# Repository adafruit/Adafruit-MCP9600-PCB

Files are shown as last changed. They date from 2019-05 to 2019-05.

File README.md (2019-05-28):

# Adafruit-MCP9600-PCB
PCB files for Adafruit MCP9600

Format is EagleCAD schematic and board layout

For more details, check out the product page at

   * https://www.adafruit.com/product/4101

Adafruit invests time and resources providing this open source design, 
please support Adafruit and open-source hardware by purchasing 
products from Adafruit!

Designed by Adafruit Industries.  
Creative Commons Attribution, Share-Alike license, check license.txt for more information
All text above must be included in any redistribution

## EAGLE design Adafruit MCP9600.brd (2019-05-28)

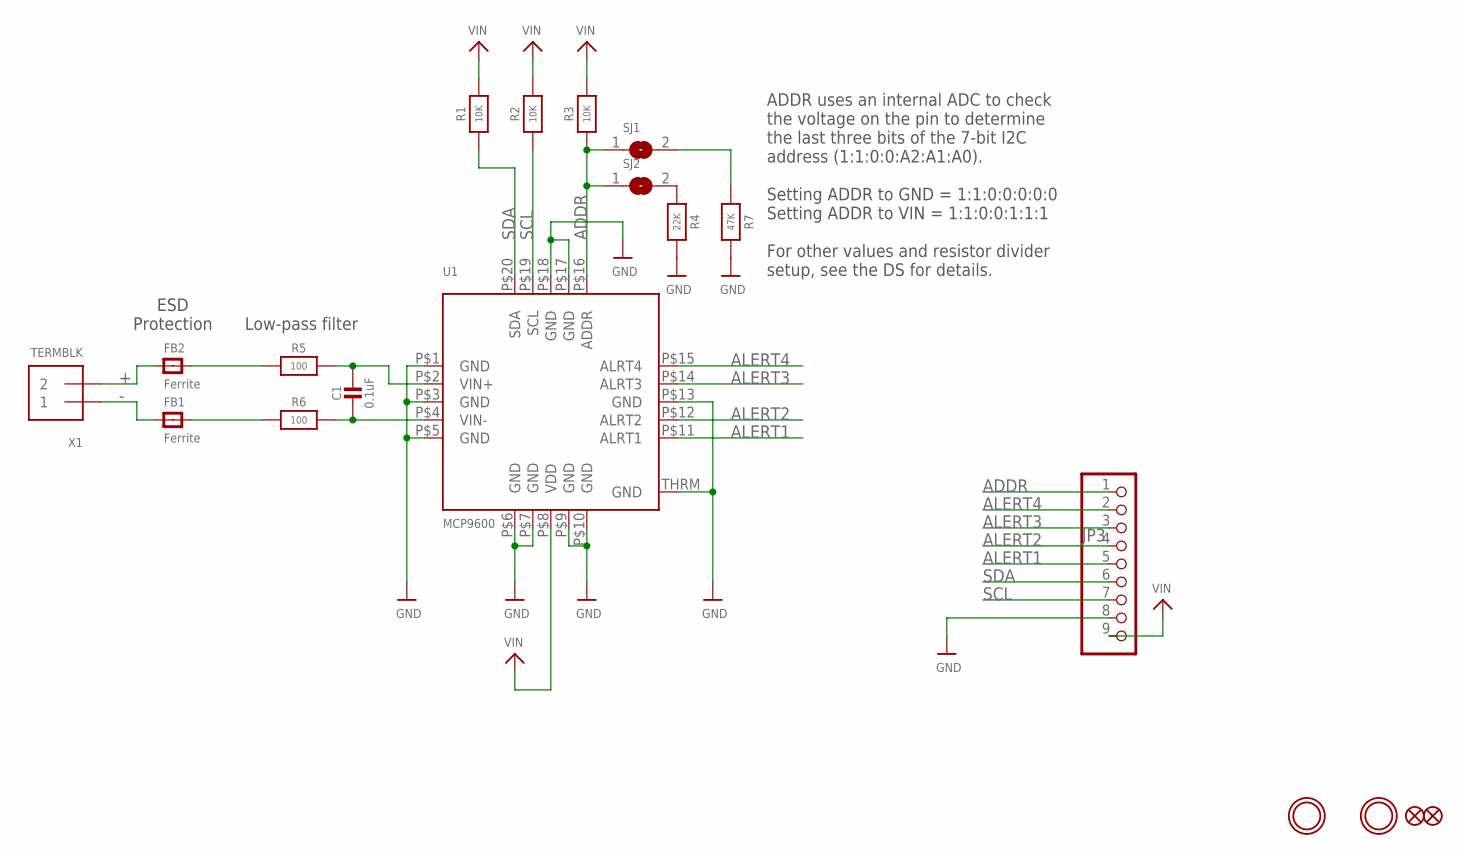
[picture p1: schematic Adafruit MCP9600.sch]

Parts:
C1: 0.1uF; 0603-NO
FB1, FB2: Ferrite; 0805-NO
FID1, FID2: FIDUCIAL_1MM
JP3: HEADER-1X970MIL; 1X09_ROUND_70
R1, R2, R3: 10K; 0603-NO
R4: 22K; 0603-NO
R5, R6: 100; 0603-NO
R7: 47K; 0603-NO
SJ1, SJ2: SOLDERJUMPER; SOLDERJUMPER_ARROW_NOPASTE
U1: MCP9600; VQFN20_5MM
U$1, U$3: MOUNTINGHOLE2.5; MOUNTINGHOLE_2.5_PLATED
X1: TERMBLK; TERMBLOCK_1X2-3.5MM

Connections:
+: FB2.1, X1.2
-: FB1.1, X1.1
ADDR: JP3.1, R3.1, SJ1.1, SJ2.1, U1.P$16 (ADDR)
ALERT1: JP3.5, U1.P$11 (ALRT1)
ALERT2: JP3.4, U1.P$12 (ALRT2)
ALERT3: JP3.3, U1.P$14 (ALRT3)
ALERT4: JP3.2, U1.P$15 (ALRT4)
GND: JP3.8, R4.2, R7.2, U1.P$1 (GND), U1.P$3 (GND), U1.P$5 (GND), U1.P$6 (GND), U1.P$7 (GND), U1.P$9 (GND), U1.P$10 (GND), U1.P$13 (GND), U1.P$17 (GND), U1.P$18 (GND), U1.THRM (GND)
unnamed: C1.1, R5.2, U1.P$2 (VIN+)
unnamed: C1.2, R6.2, U1.P$4 (VIN-)
unnamed: FB1.2, R6.1
unnamed: FB2.2, R5.1
unnamed: R7.1, SJ1.2
unnamed: R4.1, SJ2.2
SCL: JP3.7, R2.1, U1.P$19 (SCL)
SDA: JP3.6, R1.1, U1.P$20 (SDA)
VIN: JP3.9, R1.2, R2.2, R3.2, U1.P$8 (VDD)

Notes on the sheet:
ADDR uses an internal ADC to check the voltage on the pin to determine the last three bits of the 7-bit I2C address (1:1:0:0:A2:A1:A0). Setting ADDR to GND = 1:1:0:0:0:0:0 Setting ADDR to VIN = 1:1:0:0:1:1:1 For other values and resistor divider setup, see the DS for details.
Low-pass filter
ESD Protection

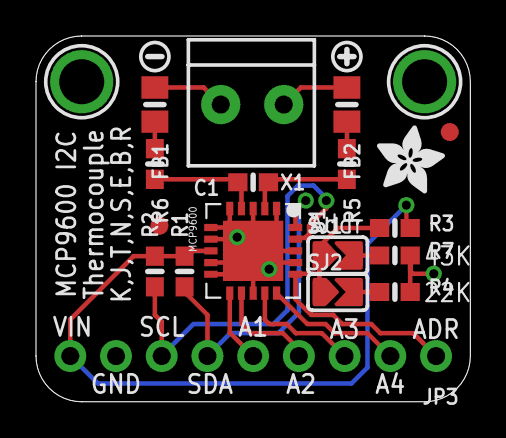
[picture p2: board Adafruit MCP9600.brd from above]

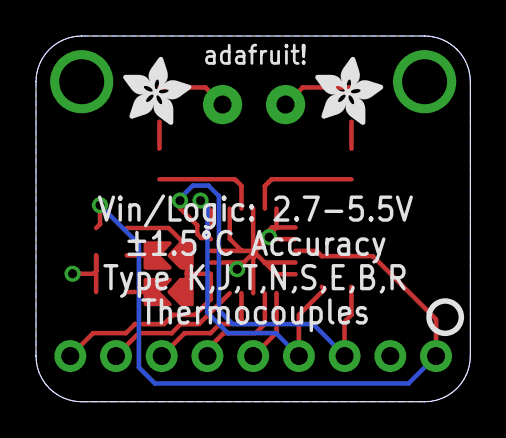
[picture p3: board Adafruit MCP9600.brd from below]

Board: 2 copper layers, 24.1 x 20.3 mm, 25 parts (3 on the bottom side), 17 nets.

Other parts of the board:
U$16, U$19, U$20: ADAFRUIT_3.5MM
U$17: SYMBOL_PLUS
U$18: SYMBOL_MINUS
U$21: PCBFEAT-REV-040

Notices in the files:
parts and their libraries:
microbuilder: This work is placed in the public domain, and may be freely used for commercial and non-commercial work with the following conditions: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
